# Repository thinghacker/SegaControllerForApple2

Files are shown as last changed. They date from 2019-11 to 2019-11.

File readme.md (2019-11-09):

# SegaControllerForApple2
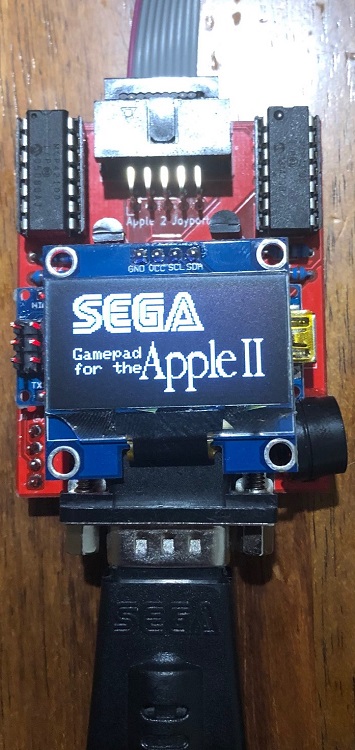
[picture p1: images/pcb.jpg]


Use a Sega Genesis/Megadrive Gamepad with your Apple 2 Computer

This repo contains the PCB details and Arduino code to be able to connect a 3 or 6 button Sega Genesis or Megadrive Gamepad to an Apple 2 Computer which utilises and Arduino Nano v3 and uses Sega Controller code by [Jon Thysell](https://github.com/jonthysell/SegaController) 

[PCB Details including Bill of Materials](pcb)

[Arduino Source Code](source)

## Theory of Operation
Apple 2 computers use two RC timer circuits to determine the position of each joystick axis. The capacitors are within the Apple 2 itself, while the resistors are variable potentiometers within the joystick.  Apple 2 computers expect the joystick to have two 150KOhm pots for X (0 = Left, 150K = Right) and Y (0 = Up, 150K = Down)

This board uses two daisy-chained MCP42100s as a means to create a 200K pot for X and Y (software limit this to 150K +/- any calibration offsets).  As this is an analog circuit, characteristics of the circuitry probably has been changed since the Apple 2 came from the factory, meaning that it is generally necessary to include an offset to wanted values for proper centering (similar to the trimmer capability on original Apple analog sticks) 

The Arduino reads the Sega Gamepad and sets the pot values to simulate analog behavior depending on the emulated joystick mode and previous states (there is a digital mode two analog styles and a hybrid mode which are selectable by clicking the Sega Controller Start Button)

Transistors are uses as switches by the arduino to trigger firebutton 0 and 1 (the method used is based on the [diagram](http://apple2.org.za/gswv/a2zine/faqs/R030PCA2RF.GIF) which was originally posted at in the official Csa2 (comp.sys.apple2) Usenet newsgroup Apple II FAQs)

If installed, the OLED provides visual feedback into the joystick operational mode and indication as to the joystick fire button and analog pot positions.

Audible feedback is also provided through the Piezo Buzzer which can be helpful when executing changes in the middle of a game.

### Gamepad Button Functions

|Button | Game Pad Mode  | When C is Held Down |
| --- | --- |--- |
| A | Firebutton 0 | Firebutton 0 Auto Fire Toggle | 
| B | Firebutton 1 | Firebutton 1 Auto Fire Toggle |
| C | Return Joystick Axes to Centre | |
| Start | Cycle Gamepad modes (Digital, Analog1, Analog2, Hybrid) | Enter Calibration Mode|
| X | Not Used |  |
| Y | Not Used |  |
| Z | Not Used |  |
| Mode | Not Used |  |

#### Notes:
Holding A/B/C together to swap Firebutton 0 and Firebutton 1

While Analog1, Analog2 and Hybrid do not re-centre when the Dpad buttons are released, pressing button C will recentre the stick.

## Calibration Mode

holding <strong>C</strong> and pressing <strong>Start</strong> on the controller will enable calibration mode.

Using the Dpad, the centre offset can be adjusted as necessary. Pressing <strong>Start</strong> will save the calibration offsets into the Arduino EEPROM and return to normal joystick mode

[ComputerInspector (MECC 1.0)](https://ftp.apple.asimov.net/images/disk_utils/diagnostics/ComputerInspector%20%28MECC%201.0%29.dsk) located on Asimov has a joystick test program which is useful to check joystick operation and to calibrate the joystick centre

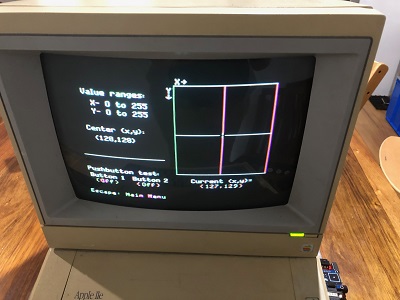
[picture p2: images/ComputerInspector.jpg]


If you are unable to download and install the image, the short Applesoft basic program below can be used to verify the board and code is working as expected and to support calibration efforts (when centred, the computer should be reporting X=128, Y=128)

###  Basic Joystick Test program from comp.sys.apple2 Apple II FAQ:
```
20 PRINT "X= "; PDL(0); TAB(15); "Y= ";PDL(1); TAB(30);
30 IF PEEK(49249)>127 THEN PRINT "  B0";
40 IF PEEK(49250)>127 THEN PRINT "  B1";
50 PRINT: GOTO 20
```

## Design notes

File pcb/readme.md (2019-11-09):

# SegaControllerForApple2

## PCB
This is a two layer through hole design.  It was made using [Kicad](http://kicad-pcb.org/) with the associated PCB source in the projects [Kicad](kicad) directory.  Gerber files are in the projects [Gerber](gerber) directory

### Assembled PCB
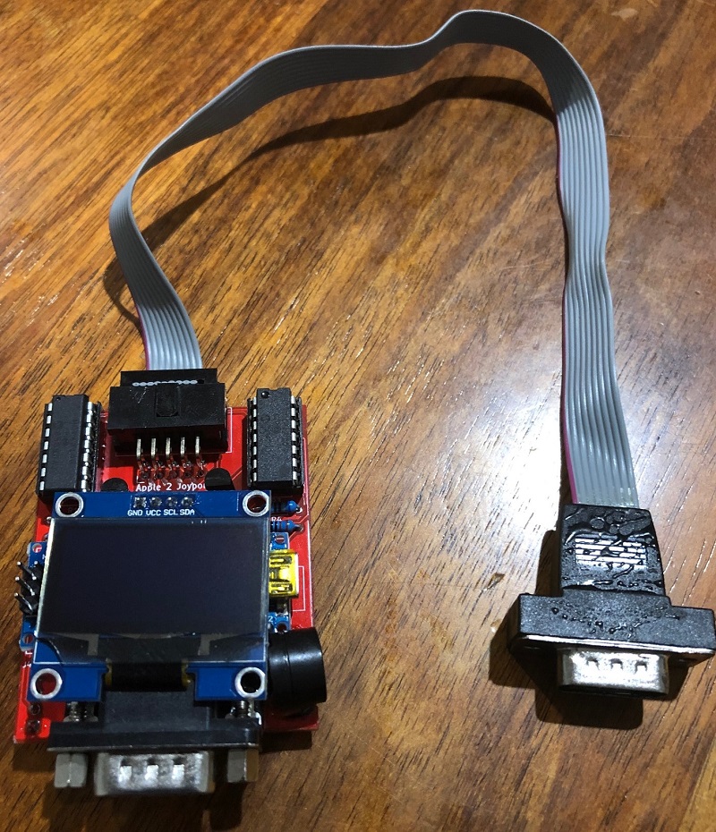
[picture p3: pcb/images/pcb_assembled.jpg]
Assembled Prototype PCB Image


Epoxy resin was applied in and around the DB9 connector of the Apple 2 Facing cable to reduce the possibility of breaking wires from the connector.

### PCB Without OLED but with Piezo Speaker
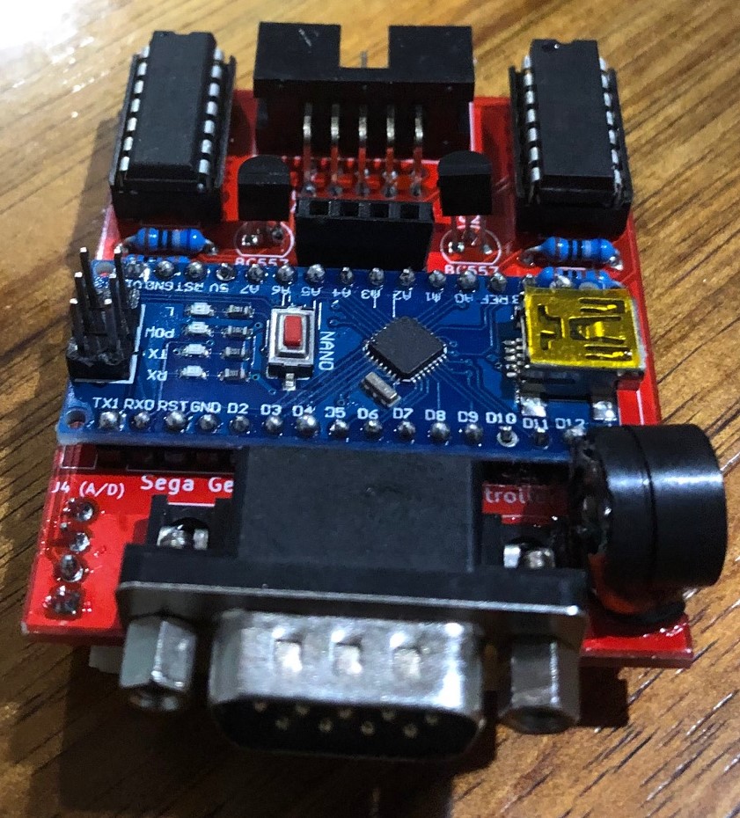
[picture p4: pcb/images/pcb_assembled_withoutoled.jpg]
PCB Without OLED but with Piezo Speaker


### PCB Top Layer
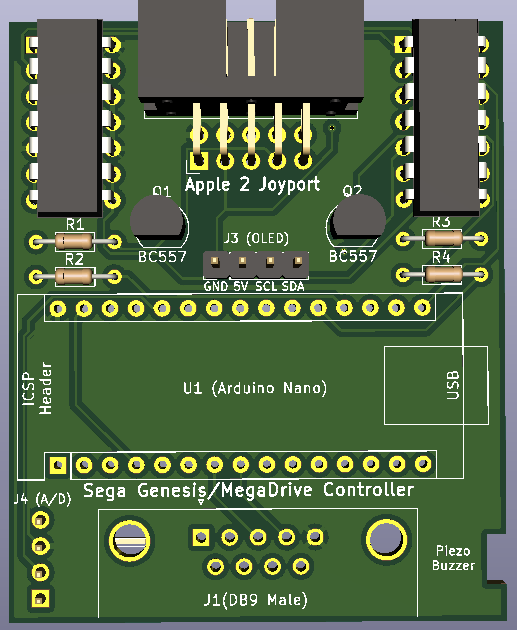
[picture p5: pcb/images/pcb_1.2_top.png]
Top Layer Image


### PCB Bottom Layer
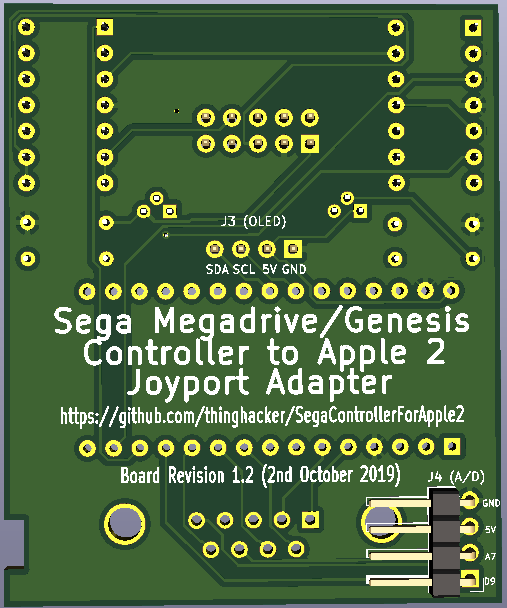
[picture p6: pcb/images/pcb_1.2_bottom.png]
Bottom Layer Image


## Bill of Materials

|Designation | Item | Description |
| --- | --- |--- |
| U1 | Ardunio Nano v3 | Controller for the system | 
| U2 | Microchip MCP42100 |Dual 100K SPI controlled Pot|
| U3 | Microchip MCP42100 |Dual 100K SPI controlled Pot|
| R1 | 680 Ohm Resistor | Resistor |
| R2 | 1K Ohm Resistor | Resistor |
| R3 | 680 Ohm Resistor | Resistor |
| R4 | 1K Ohm Resistor | Resistor |
| Q1 | BC557 Transistor| PNP Transistor |
| Q2 | BC557 Transistor| PNP Transistor |
| J1 | DB9 Male Right Angle PCB Mount Socket | Connects to Sega Gamepad |
| J2 | IDC-10 Right Angle PCB Mount Connector | Apple 2 Gameport Cable Connector |
| J3 | 4x1 Row Connector (Socket)| OLED Display Connector |
| J4 | 4x1 Row Right Angle Connector (Pins)| A/D Breakout (Usually connecting to a Piezo Buzzer) |
| C1 | PC IDC-10 to DB9 Serial Breakout Cable (usually found as two connected to a computer card edge connector | Connects from PCB to Apple 2 Gameport |
| O1 | SH1106 1.3" OLED (Optional) | PCB Display |
| P1 | PC Speaker - Piezo Buzzer (Optional) | PCB Display |

### C1 - Typically Sourced on Card Edge Connector (Only 1 cable required)
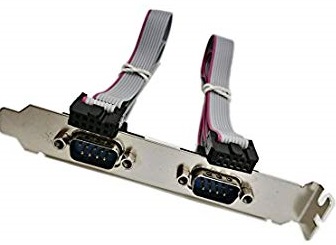
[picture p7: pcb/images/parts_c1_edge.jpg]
C1 - Typical Source on Card Edge Connector


### O1 - SH1106 1.3" OLED
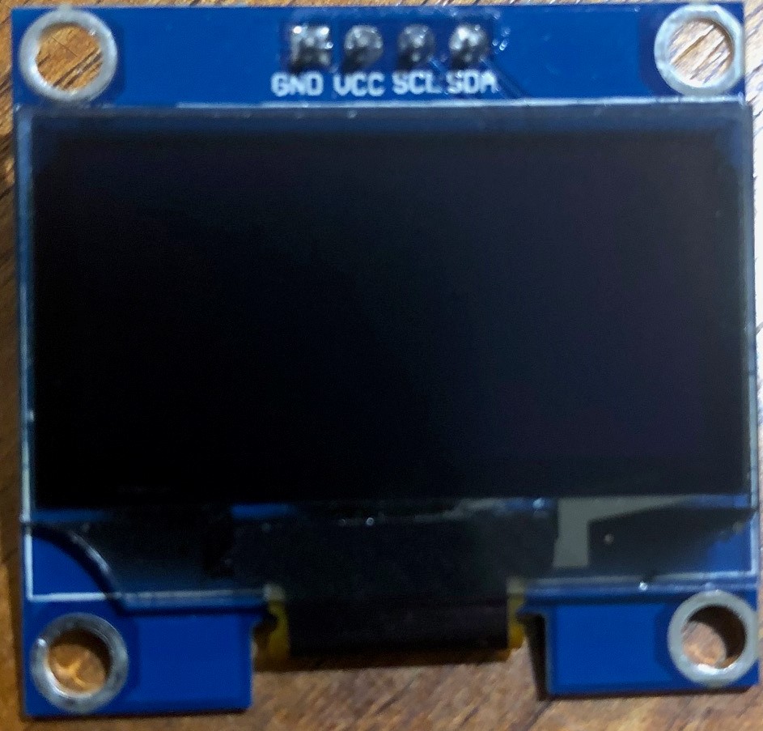
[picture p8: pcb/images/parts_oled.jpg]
O1 - SH1106 1.3" OLED


### P1 - PC Speaker - Piezo Buzzer
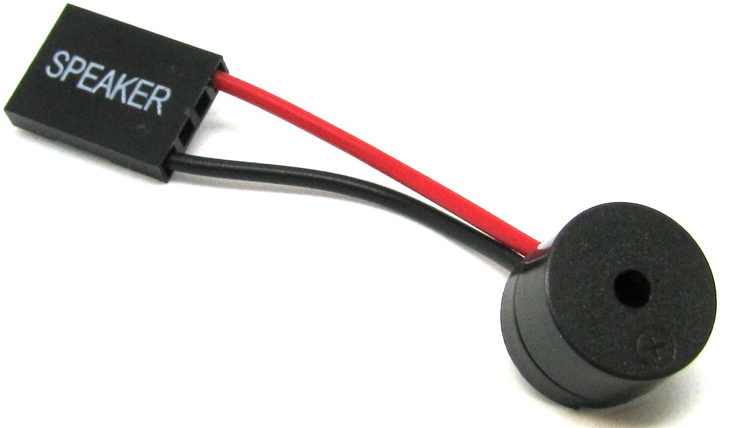
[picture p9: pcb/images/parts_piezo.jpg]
P1 - PC Speaker - Piezo Buzzer


## Construction Notes
This PCB does not require advanced soldering skills and can be assembled relatively quickly, however it may be best to work with an experienced friend or watch some youtube videos on build techniques if you are uncomfortable with soldering.

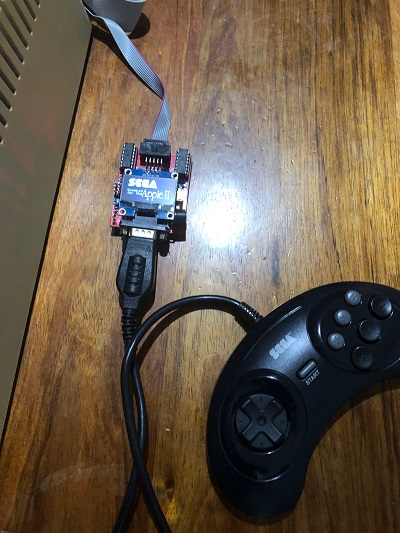
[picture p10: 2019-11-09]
images/board.jpg

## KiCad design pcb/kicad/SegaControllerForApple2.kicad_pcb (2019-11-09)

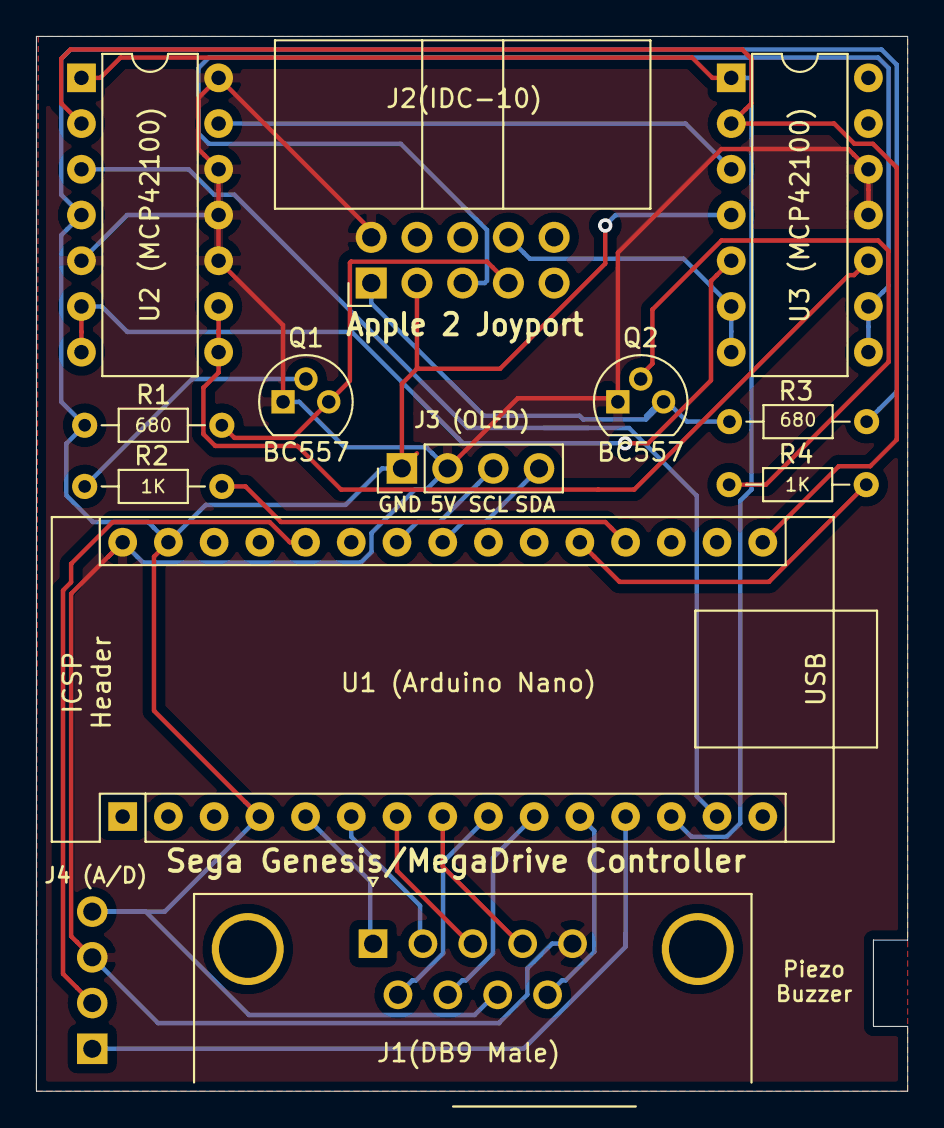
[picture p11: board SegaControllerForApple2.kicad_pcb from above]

Board: 2 copper layers, 48.4 x 58.6 mm, 13 parts (1 on the bottom side), 27 nets.

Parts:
J1(DB9 Male): Conn_02x05_Odd_Even; DSUB-9_Male_Horizontal_P2.77x2.84mm_EdgePinOffset4.94mm_Hou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
J2(IDC-10): Conn_02x05_Odd_Even; IDC-Header_2x05_P2.54mm_Horizontal
J3(OLED)1: Conn_01x04_Female; PinHeader_1x04_P2.54mm_Vertical
J4(A/D_Breakout)1: Conn_01x04_Male; PinHeader_1x04_P2.54mm_Horizontal
Q1, Q2: BC557; TO-92
R1, R3: 680; R_Axial_DIN0204_L3.6mm_D1.6mm_P7.62mm_Horizontal
R2, R4: 1K; R_Axial_DIN0204_L3.6mm_D1.6mm_P7.62mm_Horizontal
U1: Arduino_Nano_v3.x; Arduino_Nano
U2: U2 (MCP42100); DIP-14_W7.62mm
U3: MCP42100; DIP-14_W7.62mm

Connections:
+5V: J1(DB9 Male).5, J2(IDC-10).2, J3(OLED)1.2, J4(A/D_Breakout)1.3, Q1.1, Q2.1, U1.30, U2.5, U2.10, U2.11, U2.12, U2.14, U3.11, U3.12
/PDL0: J2(IDC-10).5, U3.8, U3.9
/PDL1: J2(IDC-10).8, U3.6, U3.7
/SW0: J2(IDC-10).7, Q1.3, R1.1
/SW1: J2(IDC-10).1, Q2.3, R3.1
GND: J1(DB9 Male).8, J2(IDC-10).3, J3(OLED)1.1, J4(A/D_Breakout)1.4, R1.2, R3.2, U1.4, U1.29, U2.4, U3.4
unnamed: J1(DB9 Male).1, U1.5
unnamed: J1(DB9 Male).2, U1.6
unnamed: J1(DB9 Male).3, U1.7
unnamed: J1(DB9 Male).4, U1.8
unnamed: J1(DB9 Male).6, U1.9
unnamed: J1(DB9 Male).7, U1.10
unnamed: J1(DB9 Male).9, U1.11
unnamed: J3(OLED)1.3, U1.24
unnamed: J3(OLED)1.4, U1.23
unnamed: J4(A/D_Breakout)1.1, U1.12
unnamed: J4(A/D_Breakout)1.2, U1.26
unnamed: Q1.2, R2.2
unnamed: Q2.2, R4.2
unnamed: R2.1, U1.19
unnamed: R4.1, U1.20
unnamed: U1.13, U2.1, U3.1
unnamed: U1.14, U2.3
unnamed: U1.16, U2.2, U3.2
unnamed: U2.6, U2.7, U3.5
unnamed: U2.8, U2.9, U3.10
unnamed: U2.13, U3.3

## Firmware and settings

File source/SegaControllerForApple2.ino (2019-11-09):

//
// SegaControllerForApple2.ino
// https://github.com/thinghacker/SegaControllerForApple2/
//
// Use a Sega Megadrive or Genesis Controller with your Apple 2
//
// Use the Sega Start Button to Cycle between Digital and two Analog like joystick modes
//  Digital Joystick Mode auto centres when a direction is released
//  Analog Joystick Mode does not auto centre, however Button "C" will centre if required
// Buttons A and B act as Fire 0 and Fire 1 respectively
//  Hold C and Press A or B to enable/disable autofire for that fire button
//  Hold C, A and B to swap Fire 0 and Fire 1
//
// Bill of Materials to populate the PCB:
//  U1 - Ardunio Nano v3
//  U2 - Microchip MCP42100 Dual Digital 100KOhm Pot
//  U3 - Microchip MCP42100 Dual Digital 100KOhm Pot
//  R1 - 680Ohm Resistor
//  R2 - 1KOhm Resistor
//  R3 - 680Ohm Resistor
//  R4 - 1KOhm Resistor
//  Q1 - BC557 PNP Transistor
//  Q2 - BC557 PNP Transistor
//  J1 - DB9 Socket (Sega Controller Receptical)
//  J2 - IDC-10 Right Angle connector (For Apple 2 Connector)
//  J3 - 4x1 Row Connector (For I2C Connected OLED Display - I prefer to use a SH1106 128x64 1.3" White Display)
//  J4 - 4x1 Row Connector (For Analog/Digital Breakout - usually Piezo Buzzer)
//
// The Fire Button Circuit used is based on the diagram http://apple2.org.za/gswv/a2zine/faqs/R030PCA2RF.GIF which was originally posted at in the official Csa2 (comp.sys.apple2) Usenet newsgroup Apple II FAQs
//
// There is a joystick tester available as part of the ComputerInspector (MECC 1.0) program - this can be found on Asimov https://ftp.apple.asimov.net/images/disk_utils/diagnostics/ComputerInspector%20%28MECC%201.0%29.dsk
//  It is quite helpful in visually confirming what the Apple thinks the joypad is doing and to program the calibration offsets

// Apple 2 Basic Controller Test program:
//  20 PRINT "X= "; PDL(0); TAB(15); "Y= ";PDL(1); TAB(30);
//  30 IF PEEK(49249)>127 THEN PRINT "  B0";
//  40 IF PEEK(49250)>127 THEN PRINT "  B1";
//  50 PRINT: GOTO 20 
//
// Modes:
//  Normal Operation:
//   Start = Cycles between Analog 1 (Fine grained steps along the x/y axis), Analog 2 (Coarser steps along the x/y axis) and Digital Modes
//   Up/Down/Left/Right = joypad moving in relevant direction (only Digital Mode auto centres when released)
//   Button A = Fire Button 0 (Hold C and Press A to enable/disable Autofire for Fire Button 0)
//   Button B = Fire Button 0 (Hold C and Press A to enable/disable Autofire for Fire Button 1)
//   Button C (Single Press) = Centres the joypad X and Y Values (Useful in Analog Modes for rapid centering)
//   Button C (Hold and Press Start) = Enter Calibration Mode
// 
//  Calibration Mode:
//   Start = Exit Calibration Mode and save modified X/Y offsets into eeprom
//   Up/Down/Left/Right = moves the x/y centering offset in relevant direction (The Centre should appear as 128/128 on the Apple 2)
//
// Acknowlegements:
//  This program uses the Adafruit inspired SH1106 library from https://github.com/wonho-maker/Adafruit_SH1106
//  This program uses the MCP42100 code from http://www.henrykoch.de/en/arduino-control-and-test-digital-potentiometer-mcp42010-on-a-breadboard
//  This program uses Sega Controller Code From https://github.com/jonthysell/SegaController
// Copyright notice for SegaController:
//
// Author:
//       Jon Thysell <thysell@gmail.com>
//
// Copyright (c) 2017 Jon Thysell <http://jonthysell.com>
//
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


#include <Wire.h>
#include <SPI.h>
#include <Arduino.h>
#include <EEPROM.h>

#include <Adafruit_GFX.h>
#include <Adafruit_SH1106.h>
#define OLED_RESET     -1 // Reset pin # (or -1 if sharing Arduino reset pin)
#define OLED_ADDR    0x3C // I2C 128x64
#define SCREEN_WIDTH 128 // OLED display width, in pixels
#define SCREEN_HEIGHT 64 // OLED display height, in pixels
Adafruit_SH1106 display(OLED_RESET);

//#define DEBUG        1 // operating in debug mode

#define piezoPin         9 // D9 is the for the Piezo Transducer
#define slaveselectpin  10 // D10 as the slave select for the MCP42100
#define initial_button0pin      A0 // A0 is used for SW0 
#define initial_button1pin      A1 // A1 is used for SW1
#define Analog1Stepping 32 // Analog Mode 1 Pot Increment/Decrement
#define Analog2Stepping 64 // Analog Mode 2 Pot Increment/Decrement
#define HybridStepping  96 // Hybrid Pot Increment/Decrement
#define potxcentre  192 // Centre
#define potycentre  192 // Centre
#define default_potxoffset  0 // Centre Offset
#define default_potyoffset  0 // Centre Offset
#define potxminval       0 
#define potxmaxval     383 
#define potyminval       0 
#define potymaxval     383

int AnalogStepsize     = Analog1Stepping; 
int button0pin = initial_button0pin;
int button1pin = initial_button1pin;
bool fireswap = false;

#define CONFIG_START 32
typedef struct
{
    char version[6]; // Store String "SEGA" (Null Terminated)
    int potxoffset;
    int potyoffset;
}   configuration_type;

#define CONFIG_VERSION "SEGA"
// loaded with DEFAULT values - may be overwritten when loaded

configuration_type CONFIGURATION = {
    CONFIG_VERSION,
    default_potxoffset,
    default_potyoffset,
};

enum MainLoopState {
  GAMEPAD,
  CALIBRATION,
} state;


enum Gamepadmodes {
  DIGITAL,
  ANALOG1,
  ANALOG2,
  HYBRID,  
} gamepadmode;

#define CROSSHAIR_BMP_WIDTH    8
#define CROSSHAIR_BMP_HEIGHT   8
#define CROSSHAIR_DISP_MULTIPLIER    (SCREEN_HEIGHT - CROSSHAIR_BMP_HEIGHT)
static const unsigned char PROGMEM CROSSHAIR_BMP [] = {
0x1C, 0x08, 0x5D, 0x77, 0x5D, 0x08, 0x1C, 0x00, 
};

#define LOGO_BMP_WIDTH    120
#define LOGO_BMP_HEIGHT   64
static const unsigned char PROGMEM LOGO_BMP [] = {
0x00, 0x00, 0x00, 0x00, 0x00, 0x00, 0x00, 0x00, 0x00, 0x00, 0x00, 0x00, 0x00, 0x00, 0x00, 0x00,
0x00, 0x00, 0x00, 0x00, 0x00, 0x00, 0x00, 0x00, 0x00, 0x00, 0x00, 0x00, 0x00, 0x00, 0x00, 0xFF,
0xE0, 0x7F, 0xF8, 0x1F, 0xFF, 0x80, 0x1F, 0x00, 0x00, 0x00, 0x00, 0x00, 0x00, 0x03, 0xFF, 0xE1,
0xFF, 0xF8, 0x7F, 0xFF, 0x80, 0x3F, 0x80, 0x00, 0x00, 0x00, 0x00, 0x00, 0x0F, 0xFF, 0xE3, 0xFF,
0xF8, 0xFF, 0xFF, 0x80, 0x7F, 0xC0, 0x00, 0x00, 0x00, 0x00, 0x00, 0x1F, 0x00, 0x07, 0xC0, 0x01,
0xF0, 0x00, 0x00, 0x71, 0xC0, 0x00, 0x00, 0x00, 0x00, 0x00, 0x1E, 0x3F, 0xE7, 0x9F, 0xF9, 0xE7,
0xFF, 0x80, 0xF5, 0xC0, 0x00, 0x00, 0x00, 0x00, 0x00, 0x3C, 0xFF, 0xE7, 0x3F, 0xF9, 0xCF, 0xFF,
0x80, 0xE4, 0xE0, 0x00, 0x00, 0x00, 0x00, 0x00, 0x39, 0xFF, 0xE7, 0x7F, 0xF9, 0xDF, 0xFF, 0x80,
0xEE, 0xE0, 0x00, 0x00, 0x00, 0x00, 0x00, 0x3B, 0xC0, 0x0F, 0x70, 0x03, 0xDC, 0x00, 0x01, 0xCE,
0x70, 0x00, 0x00, 0x00, 0x00, 0x00, 0x3B, 0xF0, 0x0F, 0x7F, 0xE3, 0xDD, 0xFF, 0x81, 0xDF, 0x70,
0x00, 0x00, 0x00, 0x00, 0x00, 0x39, 0xFF, 0x0F, 0x7F, 0xE3, 0xDD, 0xFF, 0x81, 0xDF, 0x70, 0x00,
0x00, 0x00, 0x00, 0x00, 0x1C, 0x7F, 0x0F, 0x7F, 0xE3, 0xDD, 0xFF, 0x83, 0x9F, 0x38, 0x00, 0x00,
0x00, 0x00, 0x00, 0x1F, 0x1F, 0x8F, 0x00, 0x03, 0xDC, 0x03, 0x83, 0xBB, 0xB8, 0x00, 0x00, 0x00,
0x00, 0x00, 0x0F, 0xC3, 0xCF, 0x7F, 0xE3, 0xDD, 0xFB, 0x87, 0xBB, 0x98, 0x00, 0x00, 0x00, 0x00,
0x00, 0x07, 0xF9, 0xEF, 0x7F, 0xE3, 0xDD, 0xFB, 0x87, 0x79, 0xDC, 0x00, 0x00, 0x00, 0x00, 0x00,
0x03, 0xFC, 0xEF, 0x7F, 0xE3, 0xDD, 0xFB, 0x87, 0x71, 0xDC, 0x00, 0x00, 0x00, 0x00, 0x00, 0x00,
0x3E, 0xEF, 0x70, 0x03, 0xDC, 0x7B, 0x8E, 0x71, 0xCE, 0x00, 0x00, 0x00, 0x00, 0x00, 0x00, 0x1E,
0xE7, 0x7F, 0xF9, 0xDF, 0xFB, 0x8E, 0xE0, 0xEE, 0x00, 0x00, 0x00, 0x00, 0x00, 0x3F, 0xFC, 0xE7,
0x7F, 0xF9, 0xDF, 0xFB, 0x9E, 0xFF, 0xEE, 0x00, 0x00, 0x00, 0x00, 0x00, 0x3F, 0xF9, 0xE7, 0x3F,
0xF9, 0xCF, 0xFB, 0x9C, 0xFF, 0xE7, 0x00, 0x00, 0x00, 0x00, 0x00, 0x3F, 0xF3, 0xC7, 0x9F, 0xF9,
0xE7, 0xFB, 0x9D, 0xFF, 0xF7, 0x00, 0x00, 0x00, 0x00, 0x00, 0x00, 0x07, 0xC3, 0xC0, 0x00, 0xF0,
0x03, 0xBD, 0xC0, 0x03, 0x80, 0x00, 0x00, 0x00, 0x00, 0x3F, 0xFF, 0x83, 0xFF, 0xF8, 0xFF, 0xFF,
0xB9, 0x9F, 0xFF, 0x80, 0x00, 0x00, 0x00, 0x00, 0x3F, 0xFE, 0x01, 0xFF, 0xF8, 0x7F, 0xFF, 0xBB,
0xBF, 0xFF, 0xC0, 0x00, 0x00, 0x00, 0x00, 0x3F, 0xF8, 0x00, 0x7F, 0xF8, 0x1F, 0xFF, 0xF3, 0xBF,
0xFF, 0xC0, 0x00, 0x00, 0x00, 0x00, 0x00, 0x00, 0x00, 0x00, 0x00, 0x00, 0x00, 0x00, 0x00, 0x00,
0x00, 0x00, 0x00, 0x00, 0x00, 0x00, 0x00, 0x00, 0x00, 0x00, 0x00, 0x00, 0x00, 0x00, 0x00, 0x00,
0x00, 0x00, 0x00, 0x00, 0x00, 0x00, 0x00, 0x00, 0x00, 0x00, 0x00, 0x00, 0x00, 0x00, 0x00, 0x00,
0x00, 0x00, 0x00, 0x00, 0x00, 0x00, 0x00, 0x00, 0x00, 0x00, 0x00, 0x00, 0x00, 0x00, 0x00, 0x00,
0x00, 0x00, 0x00, 0x00, 0x00, 0x00, 0x00, 0x00, 0x00, 0x00, 0x00, 0x00, 0x00, 0x00, 0x00, 0x00,
0x00, 0x00, 0x00, 0x00, 0x00, 0x00, 0x00, 0x00, 0x00, 0x00, 0x00, 0x00, 0x00, 0x00, 0x00, 0x00,
0x00, 0x00, 0x00, 0x00, 0x00, 0x00, 0x20, 0x00, 0x00, 0x00, 0x03, 0x00, 0x00, 0x7E, 0xFC, 0x00,
0x00, 0x00, 0x00, 0x00, 0x00, 0x20, 0x00, 0x00, 0x00, 0x07, 0x00, 0x00, 0x3C, 0x78, 0x00, 0x00,
0x00, 0x00, 0x00, 0x00, 0x20, 0x00, 0x00, 0x00, 0x03, 0x00, 0x00, 0x18, 0x30, 0x00, 0x00, 0x00,
0x00, 0x00, 0x00, 0x60, 0x00, 0x00, 0x00, 0x03, 0x00, 0x00, 0x18, 0x30, 0x00, 0x00, 0x00, 0x00,
0x00, 0x00, 0x70, 0x00, 0x00, 0x00, 0x03, 0x00, 0x00, 0x18, 0x30, 0x00, 0x00, 0x00, 0x00, 0x00,
0x00, 0x70, 0x00, 0x00, 0x00, 0x03, 0x00, 0x00, 0x18, 0x30, 0x00, 0x00, 0x00, 0x00, 0x00, 0x00,
0xF0, 0x00, 0x00, 0x00, 0x03, 0x00, 0x00, 0x18, 0x30, 0x00, 0x00, 0x00, 0x00, 0x00, 0x00, 0xB8,
0x05, 0xE0, 0x2F, 0x03, 0x07, 0xC0, 0x18, 0x30, 0x00, 0x00, 0x00, 0x00, 0x00, 0x00, 0xB8, 0x0F,
0xF0, 0x7F, 0x83, 0x0C, 0x60, 0x18, 0x30, 0x00, 0x00, 0x00, 0x00, 0x00, 0x01, 0x38, 0x1F, 0xF8,
0xFF, 0xC3, 0x18, 0x30, 0x18, 0x30, 0x00, 0x00, 0x00, 0x00, 0x00, 0x01, 0x18, 0x3C, 0x39, 0xE1,
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
};


#include <SegaController.h>

//                  DB9 Pin 7,  1,  2,  3,  4,  6,  9
SegaController controller  (7,  2,  3,  4 , 5 , 6 , 8 );

// Sega Controller states
word currentState = 0;
word lastState = 0;
bool oldjoypad_startstate = LOW;
bool oldjoypad_leftstate = LOW;
bool oldjoypad_rightstate = LOW;
bool oldjoypad_upstate = LOW;
bool oldjoypad_downstate = LOW;


// Apple 2 Gameport states
int potx = potxcentre;
int oldpotx = potx;
int poty = potycentre;
int oldpoty = poty;
bool sw0 = HIGH;
bool oldsw0 = sw0;
bool sw1 = HIGH;
bool oldsw1 = sw1;
bool gamepadconnect = LOW;
bool oldgamepadconnect = HIGH;
bool sw0autofire = false;
bool oldsw0autofire = LOW;
bool sw1autofire = false;
bool oldsw1autofire = LOW;
bool oldc_start = LOW;
bool oldc_fireswap = LOW;


void oleddisplay(word currentState) {
  char buf[40];
  display.clearDisplay();
  display.setTextSize(1);
  display.setTextColor(WHITE);

#ifdef DEBUG
  display.setCursor(0,0);
  display.print((currentState & SC_CTL_ON)    ? "+" : "-");
  display.print((currentState & SC_BTN_UP)    ? "U" : "0");
  display.print((currentState & SC_BTN_DOWN)  ? "D" : "0");
  display.print((currentState & SC_BTN_LEFT)  ? "L" : "0");
  display.print((currentState & SC_BTN_RIGHT) ? "R" : "0");
  display.print((currentState & SC_BTN_START) ? "S" : "0");
  display.print((currentState & SC_BTN_A)     ? "A" : "0");
  display.print((currentState & SC_BTN_B)     ? "B" : "0");
  display.print((currentState & SC_BTN_C)     ? "C" : "0");
  display.print((currentState & SC_BTN_X)     ? "X" : "0");
  display.print((currentState & SC_BTN_Y)     ? "Y" : "0");
  display.print((currentState & SC_BTN_Z)     ? "Z" : "0");
  display.print((currentState & SC_BTN_MODE)  ? "M" : "0");

  display.setCursor(0,16);
  //sprintf(buf, "X: %03d Y: %03d", potx, poty);
  display.print ("X: ");
  display.print (potx);
  display.print (" Y: ");
  display.println (poty);
  display.setCursor(0,24);
  display.print ("XO: ");
  display.print (CONFIGURATION.potxoffset);
  display.print (" YO: ");
  display.println (CONFIGURATION.potyoffset);
  display.setCursor(0,32);
  display.print("SW0: ");
  display.print((sw0) ? "+" : "-");
  display.print((sw0autofire) ? "A" : " ");
  display.print(" SW1: ");
  display.print((sw1) ? "+" : "-");
  display.print((sw1autofire) ? "A" : " ");

  display.setCursor(0,40);
  display.print("State: ");
  switch(state){
    case(GAMEPAD):
      display.println("Gamepad");
      break;
    case(CALIBRATION):
      display.println("Calibration");
      break;
  }
  display.setCursor(0,48);
  display.print("Mode ");
  switch(gamepadmode){
    case(DIGITAL):
      sprintf(buf, "Digital");
      break;
    case(ANALOG1):
      sprintf(buf, "Analog 1");
      break;
    case(ANALOG2):
      sprintf(buf, "Analog 2");
      break;       
    case(HYBRID):
      sprintf(buf, "Hybrid");
      break;       
  }
  display.println(buf);
  
  display.display();   
#else
  // Normal Running Code
  if (!gamepadconnect){
    display.setCursor(0,SCREEN_HEIGHT/2-8);
    display.setCursor((SCREEN_WIDTH - 5 * (strlen("SEGA Gamepad is not")+1))/2 , SCREEN_HEIGHT/2 - 8);
    display.println("SEGA Gamepad is not");  
    display.setCursor((SCREEN_WIDTH - 5 * (strlen("connected")+1))/2 , SCREEN_HEIGHT/2);
    display.println("connected");  
    display.display();   
    }
  else{
    display.drawRect(SCREEN_WIDTH - SCREEN_HEIGHT, 0, SCREEN_HEIGHT, SCREEN_HEIGHT , WHITE);
    display.setCursor(12,12);
    display.print("SW0: ");
    display.print((sw0) ? "+" : "-");
    display.print((sw0autofire) ? "A" : " ");
    display.setCursor(12,24);
    display.print("SW1: ");
    display.print((sw1) ? "+" : "-");
    display.print((sw1autofire) ? "A" : " ");
    if (fireswap){
      display.setCursor(4,32);
      display.print("ButtonSwap");      
    }
    display.setCursor(18,48);
    display.print("Mode");
    switch(state){
      case(CALIBRATION):
        display.setCursor(4,56);
        display.println("Calibrate");
        display.setCursor(72,12);
        display.print("X Offset");
        display.setCursor(85,22);
        display.print(CONFIGURATION.potxoffset);
        display.setCursor(72,32);
        display.print("Y Offset");
        display.setCursor(85,42);
        display.print(CONFIGURATION.potyoffset);
        break;
      case(GAMEPAD):
        display.drawBitmap(SCREEN_WIDTH - SCREEN_HEIGHT + (CROSSHAIR_DISP_MULTIPLIER * potx) / 384 , (CROSSHAIR_DISP_MULTIPLIER * poty) / 384,
                           CROSSHAIR_BMP, CROSSHAIR_BMP_WIDTH, CROSSHAIR_BMP_HEIGHT, WHITE);       
        display.setCursor(8,56);
        switch(gamepadmode){
          case(DIGITAL):
            display.print("Digital");
            break;
          case(ANALOG1):
            display.print("Analog 1");
            break;
          case(ANALOG2):
            display.print("Analog 2");
            break;       
          case(HYBRID):
            display.print("Hybrid");
            break;       
        } 
        break;
    }
    display.display();        
  }
  if (oldgamepadconnect != gamepadconnect){
    oldgamepadconnect = gamepadconnect;
    tone(piezoPin, 440, 20);
  }
#endif
}

void DualMSP42010PotXWrite (int xvalue) {
  // take the SS pin low to select the chip:
  digitalWrite(slaveselectpin,LOW);
  if (xvalue < 0){
    xvalue = 0;
  }
  int x1, x2;

  if (xvalue > 255){
    x1 = 255;
    x2 = xvalue-255;
  }
  else {
    x1 = xvalue;
    x2 = 0;      
  }

  //  set the value of MCP42100 #1 Pot 0 (x)
  SPI.transfer(B00010001);
  SPI.transfer(x1);
  //  set the value of MCP42100 #0 Pot 0 (x)
  SPI.transfer(B00010001);
  SPI.transfer(x2);
  // take the SS pin high to de-select the chip:
  digitalWrite(slaveselectpin,HIGH);
}


void DualMSP42010PotYWrite (int yvalue) {
  // take the SS pin low to select the chip:
  digitalWrite(slaveselectpin,LOW);
  if (yvalue < 0){
    yvalue = 0;
  }
  int y1, y2;

  if (yvalue > 255){
    y1 = 255;
    y2 = yvalue-255;
  }
  else {
    y1 = yvalue;
    y2 = 0;      
  }

  //  set the value of MCP42100 #1 Pot 1 (y)
  SPI.transfer(B00010010);
  SPI.transfer(y1);
  //  set the value of MCP42100 #0 Pot 1 (y)
  SPI.transfer(B00010010);
  SPI.transfer(y2);
  // take the SS pin high to de-select the chip:
  digitalWrite(slaveselectpin,HIGH);
}

int loadConfig() {
    // Look for "SEGA" to see if we have a config already present
    if (EEPROM.read(CONFIG_START + 0) == CONFIG_VERSION[0] &&
        EEPROM.read(CONFIG_START + 1) == CONFIG_VERSION[1] &&
        EEPROM.read(CONFIG_START + 2) == CONFIG_VERSION[2] &&
        EEPROM.read(CONFIG_START + 3) == CONFIG_VERSION[3]) {
        // load (overwrite) the local configuration struct
        for (unsigned int i = 0; i < sizeof(CONFIGURATION); i++) { * ((char * ) & CONFIGURATION + i) = EEPROM.read(CONFIG_START + i);
        }
        return 1; // return 1 if config loaded 
    }
    return 0; // return 0 if config NOT loaded
}

// save the CONFIGURATION in to EEPROM
void saveConfig() {
    for (unsigned int i = 0; i < sizeof(CONFIGURATION); i++)
        EEPROM.write(CONFIG_START + i, * ((char * ) & CONFIGURATION + i));
}

void setup() {
  // set the buttons as an output:
  pinMode (button0pin, OUTPUT);
  digitalWrite (button0pin, !sw0);
  pinMode (button1pin, OUTPUT);
  digitalWrite (button1pin, !sw1);
  // set the slaveselectpin as an output:
  pinMode (slaveselectpin, OUTPUT);
 
  loadConfig(); // obtain the offsets
  potx = potxcentre;
  poty = potycentre;

  // initialize SPI:
  SPI.begin();
  DualMSP42010PotXWrite(potx + CONFIGURATION.potxoffset);
  DualMSP42010PotYWrite(poty + CONFIGURATION.potyoffset);

  pinMode(piezoPin,OUTPUT);
  display.begin(SH1106_SWITCHCAPVCC, OLED_ADDR);  // initialize with the I2C addr 0x3D (for the 128x64)    
  display.clearDisplay();
  display.display();
  display.drawBitmap(
    (SCREEN_WIDTH  - LOGO_BMP_WIDTH ) / 2,
    0, LOGO_BMP, LOGO_BMP_WIDTH, LOGO_BMP_HEIGHT, 1);

  display.setTextSize(1);
  display.setTextColor(WHITE);
  display.setCursor(6,35);
  display.print("Gamepad");
  display.setCursor(6,44);
  display.print("for the");

  // update display with all of the above graphics
  display.display();
  delay(6000);

}
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
void loop() {
  currentState = controller.getState();
  if (currentState != lastState)
  {
    lastState = currentState;
  }
  gamepadconnect = (currentState & SC_CTL_ON) ? HIGH : LOW;
  switch(state){
    case(GAMEPAD):
      gamepad();
      break;
    case(CALIBRATION):
      potcalibration();
      break;
  }
  if (currentState != lastState)
  {
    lastState = currentState;
  }
  // Update pot values
  DualMSP42010PotXWrite(potx + CONFIGURATION.potxoffset);
  DualMSP42010PotYWrite(poty + CONFIGURATION.potyoffset);
  // Update Fire Buttons
  if (sw0 != oldsw0)
  {
    oldsw0 = sw0;
    digitalWrite(button0pin, !sw0);
  }
  if (sw1 != oldsw1)
  {
    oldsw1 = sw1;
    digitalWrite(button1pin, !sw1);
  }  
  oleddisplay(currentState);
}
